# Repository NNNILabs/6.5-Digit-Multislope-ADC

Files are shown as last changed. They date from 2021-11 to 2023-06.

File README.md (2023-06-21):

# 6.5 Digit Multislope ADC
## Analog to digital converter than can resolve voltages down to 10uV

#### About

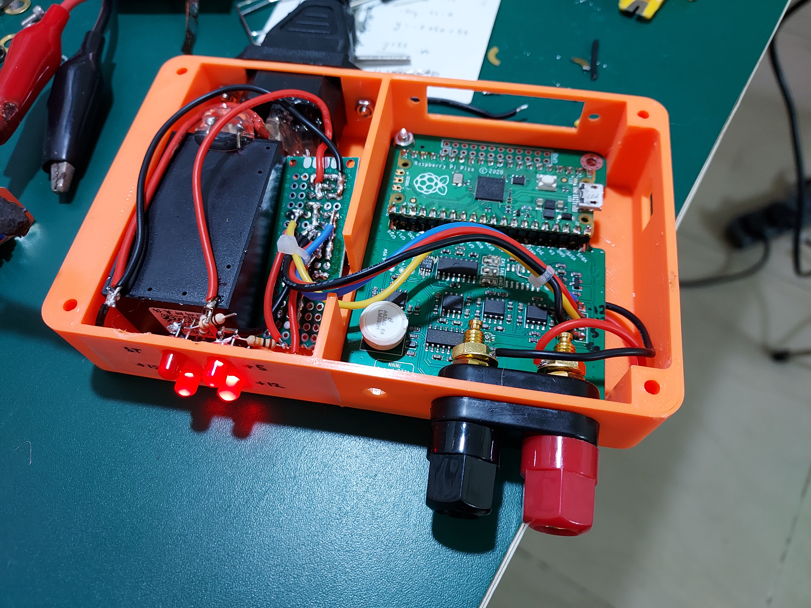
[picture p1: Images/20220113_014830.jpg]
ADC


The multislope topology fits comfortably between dual-slope and delta-sigma methods - very few precision components are needed to get very good results. Multislope is a charge balancing method - the input voltage is converted to a current (through the input resistor, one side of which is a virtual ground) and fed continuously into the integrator, and positive and negative reference voltages (which are converted to currents in the same way) are periodically injected into the integrator to maintain net zero charge. This is made possible using a clocked zero crossing comparator which determines which reference is to be switched into the inetgrator every clock cycle. 

This ADC has all the basic parts needed to operate it as a standalone +/-10V digitizer - an LM399 voltage reference, ref amps that convert the reference voltage to +/-10V, an input multiplexer, an input buffer, and the basic multislope components - a resistor network, an analog switch, a composite integrator, a fast comparator and a D latch. Using the on-board jumpers, this board can be configured to run in the "free-running" state (which can be considered a rudimentary delta-sigma method) and in PWM mode, with a constant number of switch transitions of remove errors due to analog switch charge injection.

Each measurement is taken over one power line cycle for normal mode rejection. The input is integrated over 6000 PWM cycles in 50Hz land and 5000 PWM cycles in 60Hz land. One power line cycle integration time gives around 16 bits resolution, 15 PLC is needed to achieve full 6.5 digits.

Each measurement cycle begins with "desaturation, which reads the comparator and slews the integrator to zero. Then the required number of PWM cycles are integrated, followed by rundown to read integrator residue. 

#### Statistics

-to be added-

#### Errata

- D Latch outputs are reversed if you want to use the ADC in free-running mode, luckily this can be changed easily by crossing over wires on the jumpers
- For the present PWM PIO code, the D latch has to be removed and the MEAS and SW-S3 pins have to be bridged together

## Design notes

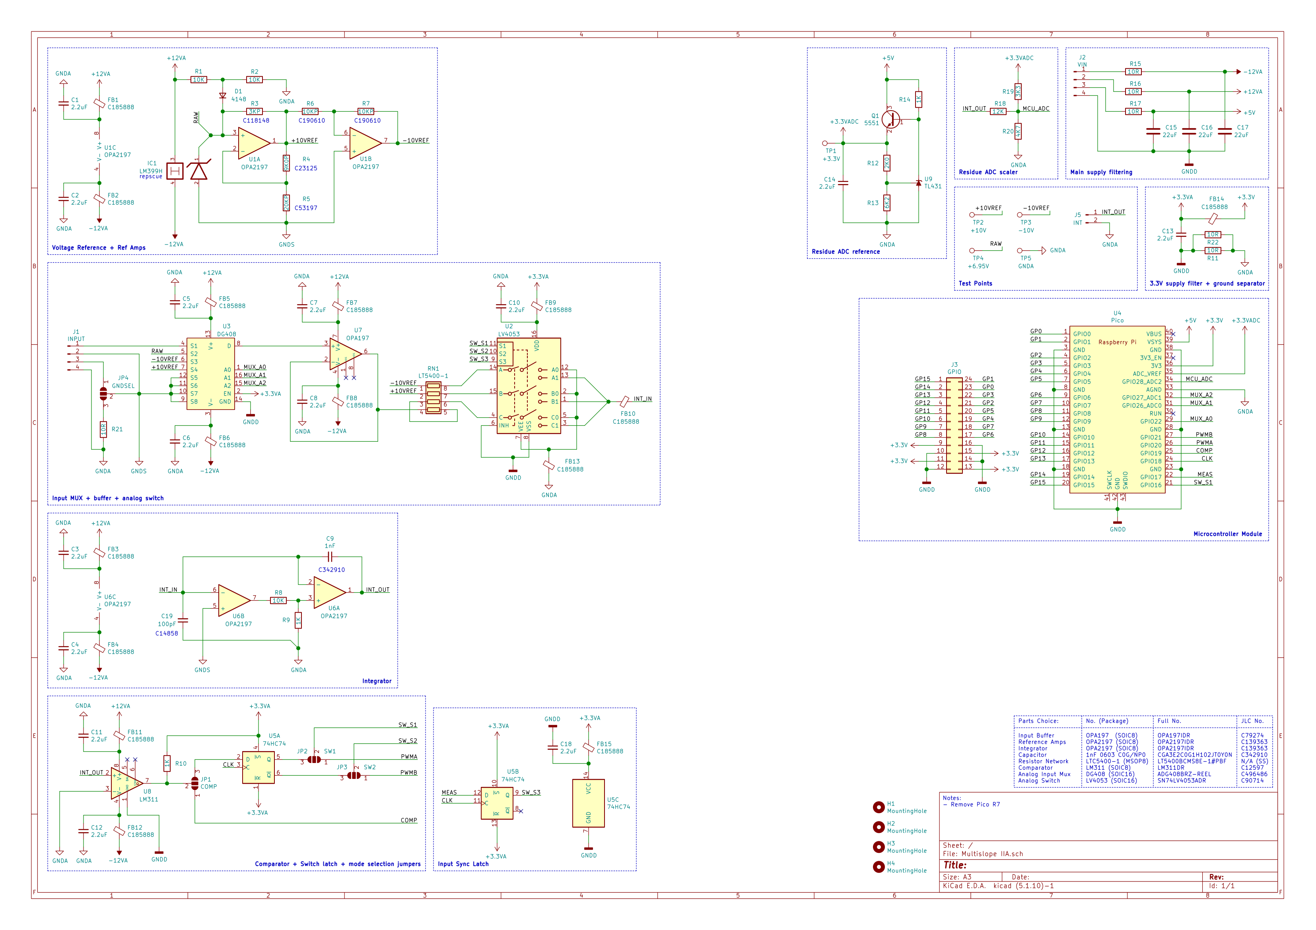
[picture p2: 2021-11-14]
PCB3/Multislope IIA-1.png

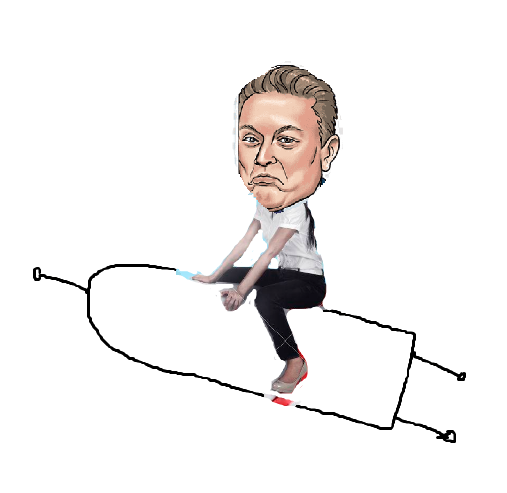
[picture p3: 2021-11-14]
PCB3/elongates.PNG

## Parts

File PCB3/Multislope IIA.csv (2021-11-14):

Comment | Designator | Footprint | LCSC Part #
2.2uF Unpolarized capacitor, small symbol | C1,C2,C3,C4,C5,C6,C7,C8,C10,C11,C12,C13,C14,C18 | C_0603_1608Metric | C23630
1nF Unpolarized capacitor, small symbol | C9 | C_0603_1608Metric | C342910
10uF Unpolarized capacitor | C15,C16,C17 | C_0603_1608Metric | C96446
100pF Unpolarized capacitor, small symbol | C19 | C_0603_1608Metric | C14858
4148 Diode, small symbol | D1 | D_SOD-323 | C2128
C185888 Ferrite bead, small symbol | FB1,FB2,FB3,FB4,FB5,FB6,FB7,FB8,FB9,FB10,FB11,FB12,FB13,FB14,FB15 | L_0603_1608Metric | C185888
MountingHole Mounting Hole without connection | H1,H2,H3,H4 | MountingHole_3mm_Pad_Via
LM399H | IC1 | TO-46-4
INPUT Generic connector, single row, 01x04, script generated (kicad-library-utils/schlib/autogen/connector/) | J1 | PinHeader_1x04_P2.54mm_Vertical
VIN Generic connector, single row, 01x04, script generated (kicad-library-utils/schlib/autogen/connector/) | J2 | PinHeader_1x04_P2.54mm_Vertical
GPIO Generic connector, double row, 02x12, counter clockwise pin numbering scheme (similar to DIP packge numbering), script generated (kicad-library-utils/schlib/autogen/connector/) | J3 | PinHeader_2x12_P2.54mm_Vertical
INT Generic connector, single row, 01x02, script generated (kicad-library-utils/schlib/autogen/connector/) | J5 | PinHeader_1x02_P1.27mm_Vertical
COMP Solder Jumper, 3-pole, open | JP1 | SolderJumper-3_P1.3mm_Open_Pad1.0x1.5mm
SW1 Solder Jumper, 3-pole, open | JP2 | SolderJumper-3_P1.3mm_Open_Pad1.0x1.5mm
SW2 Solder Jumper, 3-pole, open | JP3 | SolderJumper-3_P1.3mm_Open_Pad1.0x1.5mm
GNDSEL Solder Jumper, 3-pole, open | JP4 | SolderJumper-3_P1.3mm_Open_Pad1.0x1.5mm
5551 NPN transistor, base/emitter/collector | Q1 | SOT-23 | C2145
10K Resistor | R1,R2,R8 | R_0603_1608Metric | C25804
3KP Resistor | R3 | R_0603_1608Metric | C118148
9K0P Resistor | R4 | R_0603_1608Metric | C23125
20KP Resistor | R5 | R_0603_1608Metric | C53197
10KP Resistor | R6,R7 | R_0603_1608Metric | C190610
1K Resistor | R9,R10,R14 | R_0603_1608Metric | C21190
10R Resistor | R11,R15,R16,R17,R21,R22 | R_0603_1608Metric | C22859
2K0 Resistor | R12 | R_0603_1608Metric | C22975
6K2 Resistor | R13 | R_0603_1608Metric | C4260
12K Resistor | R18 | R_0603_1608Metric | C22790
3K3 Resistor | R19 | R_0603_1608Metric | C22978
4K7 Resistor | R20 | R_0603_1608Metric | C23162
LT5400-1 4 resistor network, parallel topology | RN1 | MSOP-8-1EP_3x3mm_P0.65mm_EP1.68x1.88mm
+3.3V test point | TP1 | TestPoint_Pad_D1.0mm
+10V test point | TP2 | TestPoint_Pad_D1.0mm
-10V test point | TP3 | TestPoint_Pad_D1.0mm
+6.95V test point | TP4 | TestPoint_Pad_D1.0mm
GNDA test point | TP5 | TestPoint_Pad_D1.0mm
OPA2197 Dual operational amplifier | U1,U6 | SOIC-8_3.9x4.9mm_P1.27mm | C139363
LV4053 CMOS triple 2-channel analog multiplexer/demultiplexer, TSSOP-16/DIP-16/SOIC-16 | U2 | SOIC-16_3.9x9.9mm_P1.27mm | C90714
DG408 | U3 | SOIC-16_3.9x9.9mm_P1.27mm | C496486
Pico | U4 | RPi_Pico_SMD_TH
74HC74 Dual D Flip-flop, Set & Reset | U5 | SOIC-14_3.9x8.7mm_P1.27mm | C6762
OPA197 Next Generation OP07 Ultralow Offset Voltage Operational Amplifier, DIP-8/TO-99-8 | U7 | SOIC-8_3.9x4.9mm_P1.27mm | C79274
LM311 Voltage Comparator, DIP-8/SOIC-8 | U8 | SOIC-8_3.9x4.9mm_P1.27mm | C12597
TL431 Shunt Regulator, SOT-23 | U9 | SOT-23 | C21235

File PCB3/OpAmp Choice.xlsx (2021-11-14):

Part Number | Package | Vos | Ib | Ios | Vos drift | en | in | Source | Single Available? | Used?
OPA2277UA/2K5 | SOIC-8 | 25uV | 4nA | 4nA | 1uV/C | 0.22uVpp, 8nV/rtHz | 0.2pA/rtHz | JLC | yes | No
OPA2180 | SOIC/SSOP8 | 75uV | 5nA | 3.5nA | 0.35uV/C | 0.25uVpp, 10nV/rtHz | 10fA/rtHz | Mouser | yes | No
OPA2197IDR | SOIC-8 | 100uV | 5nA | 2nA | 4.5uV/C | 1.3uVpp, 5.5nV/rtHz | 1.5fA/rtHz | JLC | yes | Yes
LT1013DDR | SOIC-8 | 400uV | 38nA | 3nA | 2.5uV/C | 0.55uVpp, 22nV/rtHz | 0.07pA/rtHz | JLC | n/a | No
OPA2227UA/2K5 | SOIC-8 | 200uV | 10nA | 10nA | 2uV/C | 90nVpp, 3nV/rtHz | 0.4pA/rtHz | JLC | expensive! | No
OPA1652AIDR | SOIC-8 | 1.5mV | 100pA | 100pA | 8uV/C | 5.4uVpp, 4.5nV/rtHz | 0.5pA/rtHz | JLC | n/a | No
OPA2211AIDDAR | SOIC-8 | 150uV | 250nA | 150nA | 0.85uV/C | 80nVpp, 1.1nV/rtHz | 1.7pA/rtHz | JLC | not in stock | No

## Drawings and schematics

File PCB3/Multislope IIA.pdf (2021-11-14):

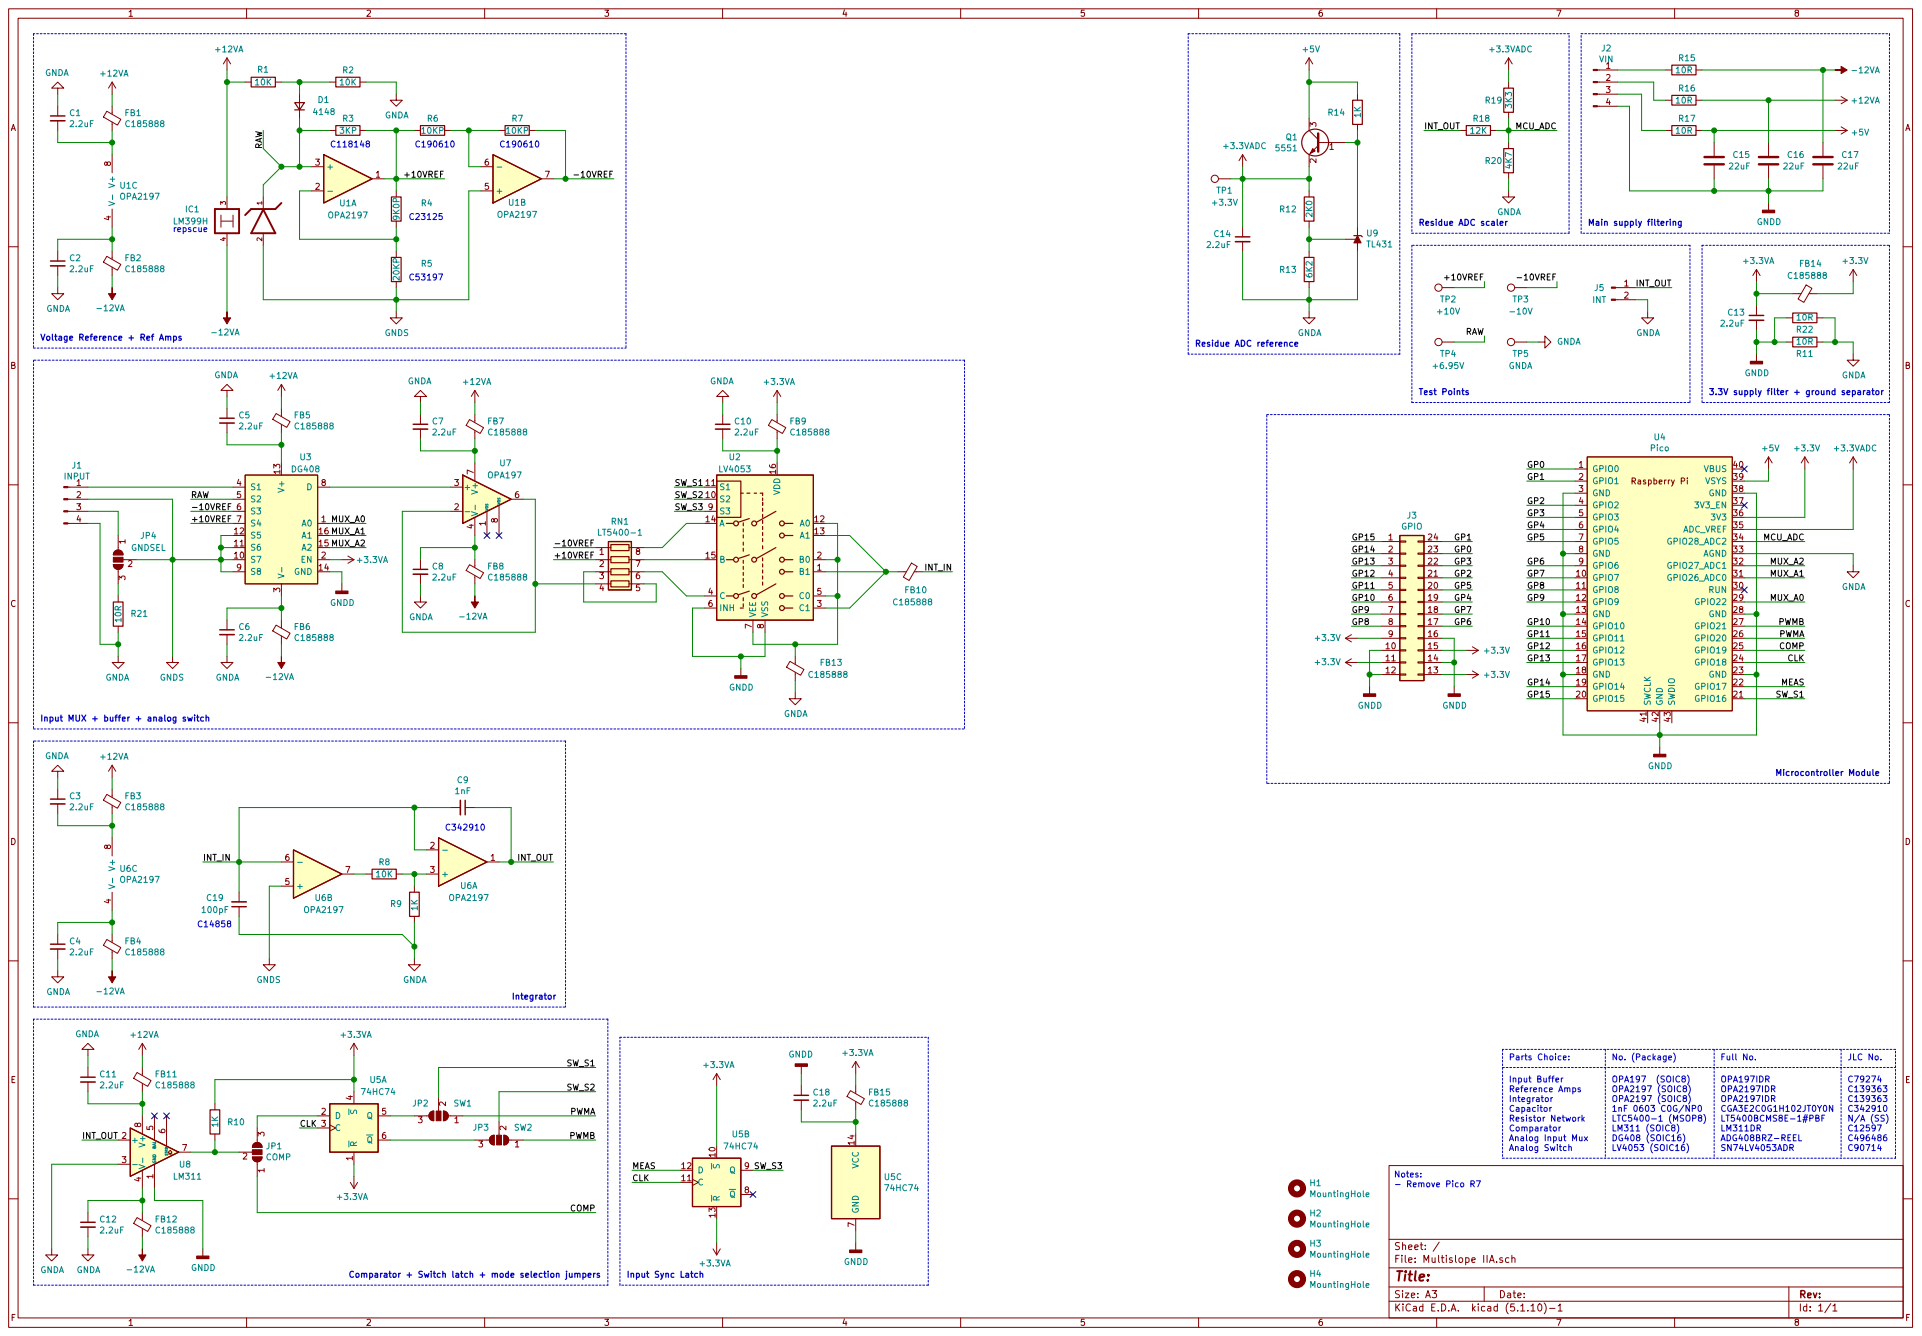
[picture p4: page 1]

Test Points Residue ADC reference Voltage Reference + Ref Amps

3.3V supply filter + ground separator C342910 Comparator + Switch latch + mode selection jumpers

Input MUX + buffer + analog switch

Analog Switch Parts Choice: Input Buffer Reference Amps Integrator Capacitor Resistor Network Comparator Analog Input Mux | OPA2197 (SOIC8) OPA2197 (SOIC8) 1nF 0603 C0G/NP0 LTC5400-1 (MSOP8) LM311 (SOIC8) DG408 (SOIC16) | OPA197IDR OPA2197IDR OPA2197IDR CGA3E2C0G1H102JT0Y0N LT5400BCMS8E-1#PBF LM311DR ADG408BRZ-REEL SN74LV4053ADR | C79274 C139363 C139363 C342910 N/A (SS) C12597 C496486 C90714 No. (Package)

Full No. | JLC No. OPA197 (SOIC8)

File: Multislope IIA.sch Sheet: /

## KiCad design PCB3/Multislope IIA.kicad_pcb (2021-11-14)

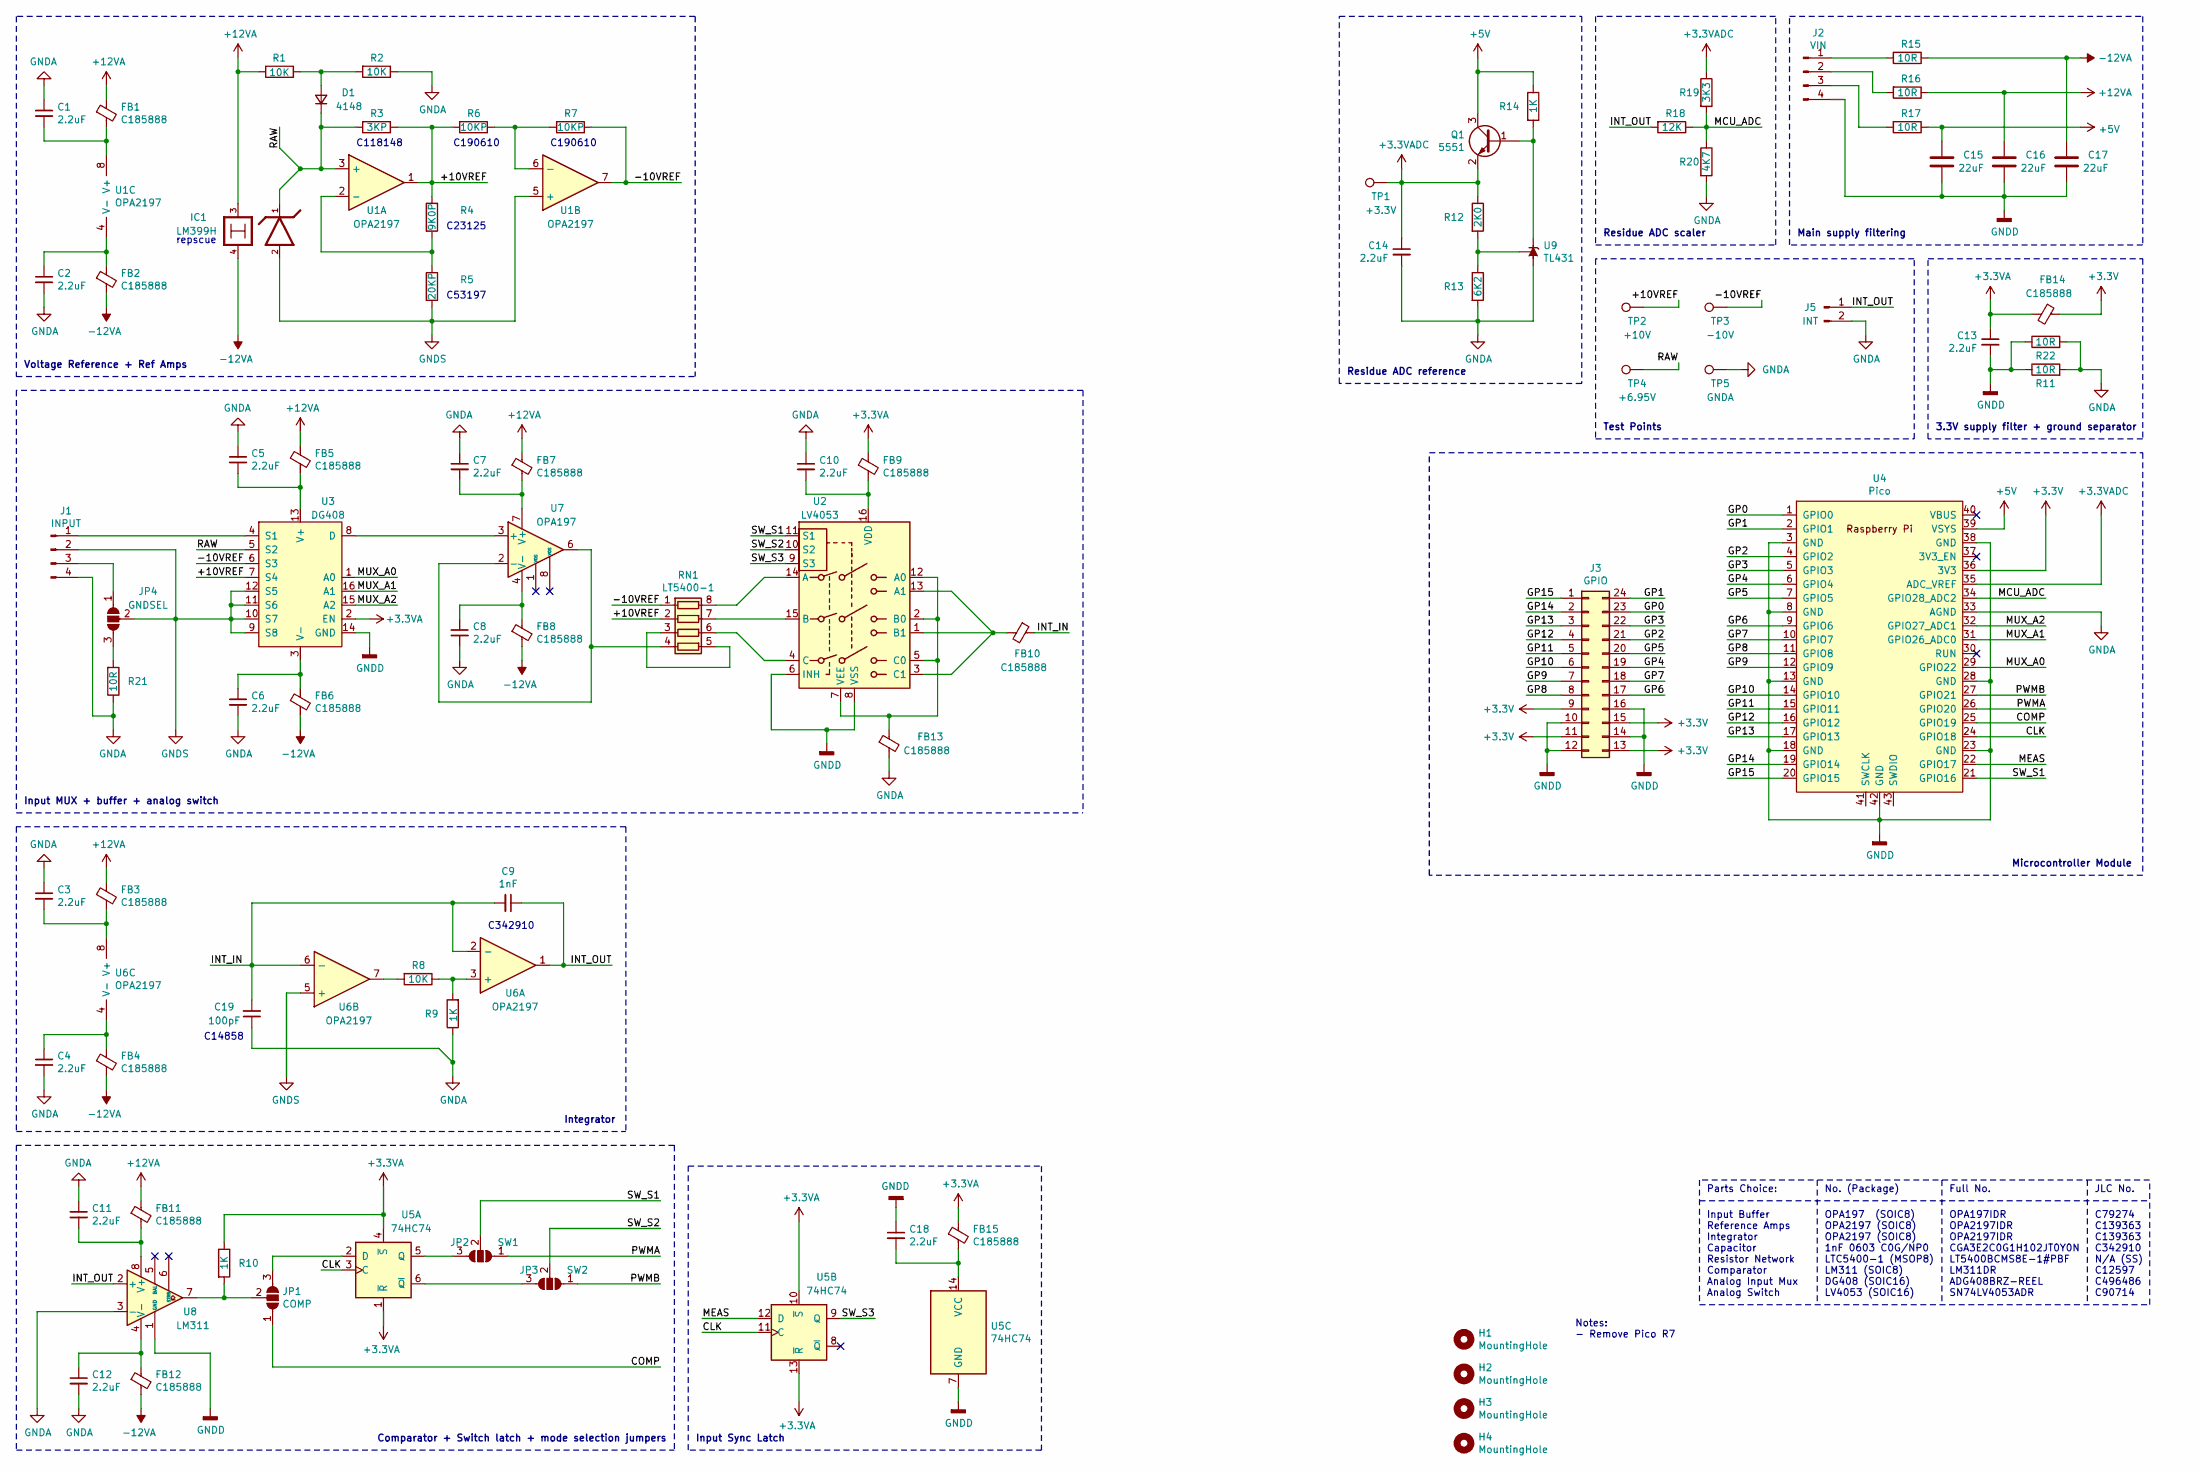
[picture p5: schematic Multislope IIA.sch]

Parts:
C1, C2, C3, C4, C5, C6, C7, C8, C10, C11, C12, C13, C14, C18: 2.2uF; C_0603_1608Metric
C9: 1nF; C_0603_1608Metric
C15, C16, C17: 22uF; C_0603_1608Metric
C19: 100pF; C_0603_1608Metric
D1: 4148; D_SOD-323
FB1, FB2, FB3, FB4, FB5, FB6, FB7, FB8, FB9, FB10, FB11, FB12, FB13, FB14, FB15: C185888; L_0603_1608Metric
H1, H2, H3, H4: MountingHole; MountingHole_3mm_Pad_Via
IC1: LM399H; TO-46-4
J1: INPUT; PinHeader_1x04_P2.54mm_Vertical
J2: VIN; PinHeader_1x04_P2.54mm_Vertical
J3: GPIO; PinHeader_2x12_P2.54mm_Vertical
J5: INT; PinHeader_1x02_P1.27mm_Vertical
JP1: COMP; SolderJumper-3_P1.3mm_Open_Pad1.0x1.5mm
JP2: SW1; SolderJumper-3_P1.3mm_Open_Pad1.0x1.5mm
JP3: SW2; SolderJumper-3_P1.3mm_Open_Pad1.0x1.5mm
JP4: GNDSEL; SolderJumper-3_P1.3mm_Open_Pad1.0x1.5mm
Q1: 5551; SOT-23
R1, R2, R8: 10K; R_0603_1608Metric
R3: 3KP; R_0603_1608Metric
R4: 9K0P; R_0603_1608Metric
R5: 20KP; R_0603_1608Metric
R6, R7: 10KP; R_0603_1608Metric
R9, R10, R14: 1K; R_0603_1608Metric
R11, R15, R16, R17, R21, R22: 10R; R_0603_1608Metric
R12: 2K0; R_0603_1608Metric
R13: 6K2; R_0603_1608Metric
R18: 12K; R_0603_1608Metric
R19: 3K3; R_0603_1608Metric
R20: 4K7; R_0603_1608Metric
RN1: LT5400-1; MSOP-8-1EP_3x3mm_P0.65mm_EP1.68x1.88mm
TP1: +3.3V; TestPoint_Pad_D1.0mm
TP2: +10V; TestPoint_Pad_D1.0mm
TP3: -10V; TestPoint_Pad_D1.0mm
TP4: +6.95V; TestPoint_Pad_D1.0mm
TP5: GNDA; TestPoint_Pad_D1.0mm
U1, U6: OPA2197; SOIC-8_3.9x4.9mm_P1.27mm
U2: LV4053; SOIC-16_3.9x9.9mm_P1.27mm
U3: DG408; SOIC-16_3.9x9.9mm_P1.27mm
U4: Pico; RPi_Pico_SMD_TH
U5: 74HC74; SOIC-14_3.9x8.7mm_P1.27mm
U7: OPA197; SOIC-8_3.9x4.9mm_P1.27mm
U8: LM311; SOIC-8_3.9x4.9mm_P1.27mm
U9: TL431; SOT-23

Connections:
+3.3VA: C13.1, FB9.1, FB14.2, FB15.1, R10.1, U3.2 (EN), U5.1 (~R), U5.4 (~S), U5.10 (~S), U5.13 (~R)
+3.3VADC: C14.1, Q1.2 (E), R12.1, R19.1, TP1.1, U4.35 (ADC_VREF)
+3V3: FB14.1, J3.9, J3.11, J3.13, J3.15, U4.36 (3V3)
+5V: C15.1, Q1.3 (C), R14.1, R17.1, U4.39 (VSYS)
+12VA: C16.1, FB1.1, FB3.1, FB5.1, FB7.1, FB11.1, IC1.3, R1.1, R16.1
-12VA: C17.1, FB2.2, FB4.2, FB6.2, FB8.2, FB12.2, IC1.4, R15.1
/+10VREF: R3.1, R4.1, R6.2, RN1.2 (R2.1), TP2.1, U1.1, U3.7 (S4)
/-10VREF: R7.1, RN1.1 (R1.1), TP3.1, U1.7, U3.6 (S3)
/CLK: U4.24 (GPIO18), U5.3 (C), U5.11 (C)
/COMP: JP1.1 (A), U4.25 (GPIO19)
/GP0: J3.23, U4.1 (GPIO0)
/GP1: J3.24, U4.2 (GPIO1)
/GP2: J3.21, U4.4 (GPIO2)
/GP3: J3.22, U4.5 (GPIO3)
/GP4: J3.19, U4.6 (GPIO4)
/GP5: J3.20, U4.7 (GPIO5)
/GP6: J3.17, U4.9 (GPIO6)
/GP7: J3.18, U4.10 (GPIO7)
/GP8: J3.8, U4.11 (GPIO8)
/GP9: J3.7, U4.12 (GPIO9)
/GP10: J3.6, U4.14 (GPIO10)
/GP11: J3.5, U4.15 (GPIO11)
/GP12: J3.4, U4.16 (GPIO12)
/GP13: J3.3, U4.17 (GPIO13)
/GP14: J3.2, U4.19 (GPIO14)
/GP15: J3.1, U4.20 (GPIO15)
/INT_IN: C9.2, C19.2, FB10.1, U6.2 (-), U6.6 (-)
/INT_OUT: C9.1, J5.1, R18.2, U6.1, U8.2 (+)
/MCU_ADC: R18.1, R19.2, R20.1, U4.34 (GPIO28_ADC2)
/MEAS: U4.22 (GPIO17), U5.12 (D)
/MUX_A0: U3.1 (A0), U4.29 (GPIO22)
/MUX_A1: U3.16 (A1), U4.31 (GPIO26_ADC0)
/MUX_A2: U3.15 (A2), U4.32 (GPIO27_ADC1)
/PWMA: JP2.1 (A), U4.26 (GPIO20)
/PWMB: JP3.1 (A), U4.27 (GPIO21)
/RAW: D1.1 (K), IC1.1, R3.2, TP4.1, U1.3 (+), U3.5 (S2)
/SW_S1: JP2.2 (C), U2.11 (S1), U4.21 (GPIO16)
/SW_S2: JP3.2 (C), U2.10 (S2)
/SW_S3: U2.9 (S3), U5.9 (Q)
GNDA: C1.1, C2.2, C3.1, C4.2, C5.1, C6.2, C7.1, C8.2, C10.1, C11.1, C12.2, C14.2, C19.1, FB13.2, J1.4, J5.2, R2.1, R9.1, R11.2, R13.2, R20.2, R21.1, R22.2, TP5.1, U4.33 (AGND), U8.3 (-), U9.3 (A)
GNDD: C13.2, C15.2, C16.2, C17.2, C18.1, J2.4, J3.10, J3.12, J3.14, J3.16, R11.1, R22.1, U2.6 (INH), U2.8 (VSS), U3.14 (GND), U4.3 (GND), U4.8 (GND), U4.13 (GND), U4.18 (GND), U4.23 (GND), U4.28 (GND), U4.38 (GND), U4.42 (GND), U5.7 (GND), U8.1 (GND)
GNDS: IC1.2, J1.2, JP4.2 (C), R5.2, U1.5 (+), U3.9 (S8), U3.10 (S7), U3.11 (S6), U3.12 (S5), U6.5 (+)
unnamed: C1.2, FB1.2, U1.8 (V+)
unnamed: C2.1, FB2.1, U1.4 (V-)
unnamed: C3.2, FB3.2, U6.8 (V+)
unnamed: C4.1, FB4.1, U6.4 (V-)
unnamed: C5.2, FB5.2, U3.13 (V+)
unnamed: C6.1, FB6.1, U3.3 (V-)
unnamed: C7.2, FB7.2, U7.7 (V+)
unnamed: C8.1, FB8.1, U7.4 (V-)
unnamed: C10.2, FB9.2, U2.16 (VDD)
unnamed: C11.2, FB11.2, U8.8 (V+)
unnamed: C12.1, FB12.1, U8.4 (V-)
unnamed: C18.2, FB15.2, U5.14 (VCC)
unnamed: D1.2 (A), R1.2, R2.2
unnamed: FB10.2, U2.1 (B1), U2.3 (C1), U2.13 (A1)
unnamed: FB13.1, U2.2 (B0), U2.5 (C0), U2.7 (VEE), U2.12 (A0)
unnamed: J1.1, U3.4 (S1)
unnamed: J1.3, JP4.1 (A)
unnamed: J2.1, R15.2
unnamed: J2.2, R16.2
unnamed: J2.3, R17.2
unnamed: JP1.2 (C), R10.2, U8.7
unnamed: JP1.3 (B), U5.2 (D)
unnamed: JP2.3 (B), U5.5 (Q)
unnamed: JP3.3 (B), U5.6 (~Q)
unnamed: JP4.3 (B), R21.2
unnamed: Q1.1 (B), R14.2, U9.1 (K)
unnamed: R4.2, R5.1, U1.2 (-)
unnamed: R6.1, R7.2, U1.6 (-)
unnamed: R8.1, R9.2, U6.3 (+)
unnamed: R8.2, U6.7
unnamed: R12.2, R13.1, U9.2 (REF)
unnamed: RN1.3 (R3.1), RN1.5 (R4.2)
unnamed: RN1.4 (R4.1), U7.2 (-), U7.6
unnamed: RN1.6 (R3.2), U2.4 (C)
unnamed: RN1.7 (R2.2), U2.15 (B)
unnamed: RN1.8 (R1.2), U2.14 (A)
unnamed: U3.8 (D), U7.3 (+)

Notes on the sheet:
C23125
C53197
C118148
Input Buffer Reference Amps Integrator Capacitor Resistor Network Comparator Analog Input Mux Analog Switch
OPA197 (SOIC8) OPA2197 (SOIC8) OPA2197 (SOIC8) 1nF 0603 C0G/NP0 LTC5400-1 (MSOP8) LM311 (SOIC8) DG408 (SOIC16) LV4053 (SOIC16)
OPA197IDR OPA2197IDR OPA2197IDR CGA3E2C0G1H102JT0Y0N LT5400BCMS8E-1#PBF LM311DR ADG408BRZ-REEL SN74LV4053ADR
C190610
C190610
repscue
C342910
Parts Choice:
C79274 C139363 C139363 C342910 N/A (SS) C12597 C496486 C90714
No. (Package)
Full No.
JLC No.
Notes: - Remove Pico R7
Voltage Reference + Ref Amps
Input MUX + buffer + analog switch
Integrator
Comparator + Switch latch + mode selection jumpers
Main supply filtering
Residue ADC reference
Residue ADC scaler
3.3V supply filter + ground separator
Input Sync Latch
Microcontroller Module
C14858
Test Points

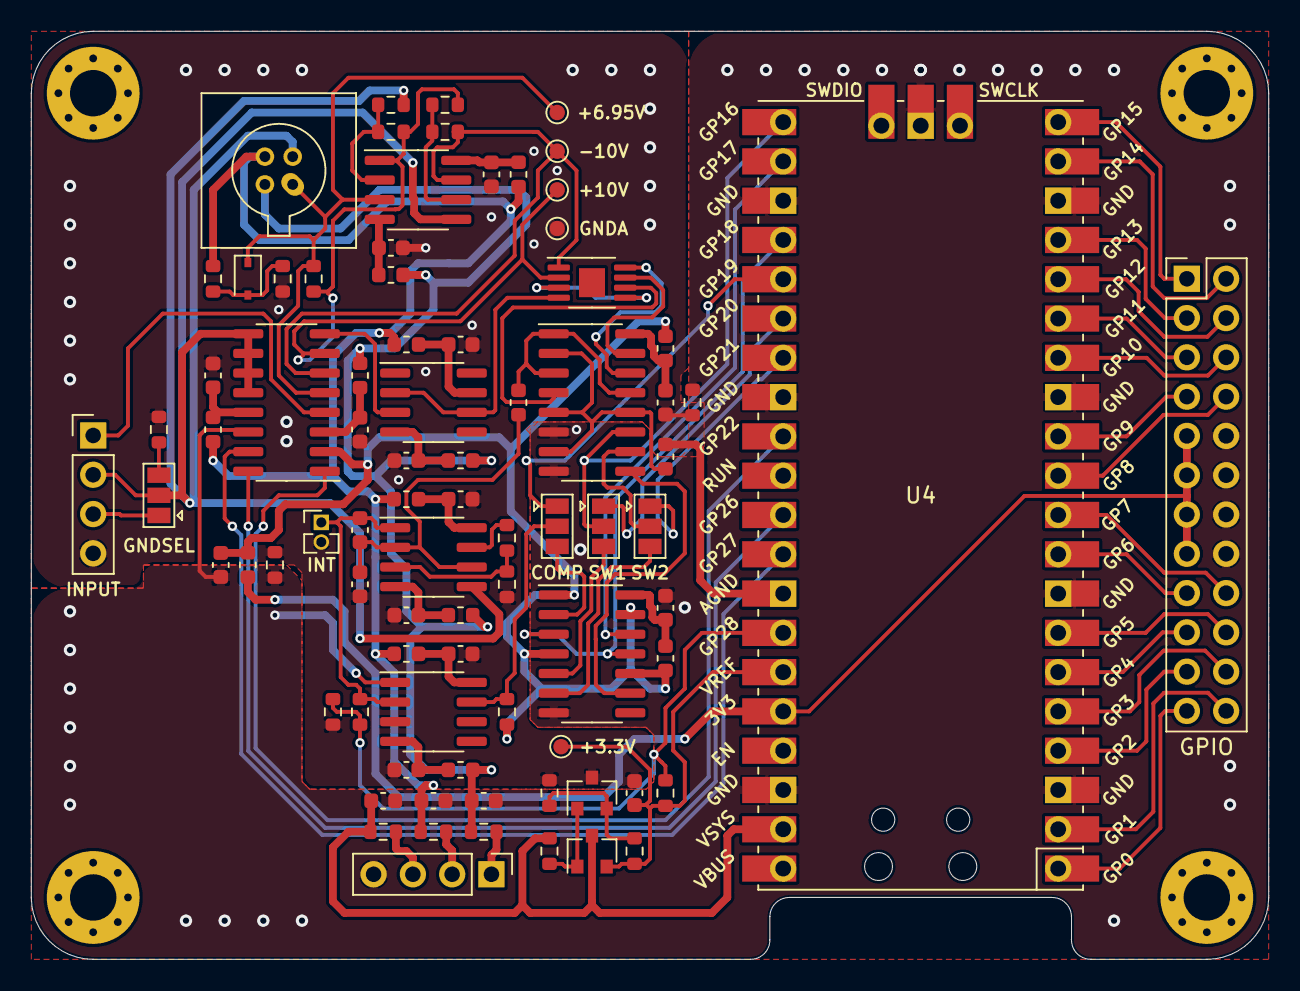
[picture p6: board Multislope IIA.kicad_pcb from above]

Board: 2 copper layers, 80.0 x 60.0 mm, 86 parts (0 on the bottom side), 79 nets.

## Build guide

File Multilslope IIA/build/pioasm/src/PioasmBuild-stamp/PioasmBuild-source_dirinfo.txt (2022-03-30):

# This is a generated file and its contents are an internal implementation detail.
# The download step will be re-executed if anything in this file changes.
# No other meaning or use of this file is supported.

method=source_dir
command=
source_dir=C:/VSARM/sdk/pico/pico-sdk/tools/pioasm
work_dir=

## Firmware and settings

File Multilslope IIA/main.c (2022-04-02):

#include "pico/stdlib.h"
#include "hardware/pio.h"
#include "hardware/clocks.h"
#include "ms.pio.h"

int main()
{
    set_sys_clock_khz(100000, true); //100Mhz main for testing, 96MHz for real thing

    static const uint ledPin = 0;
    static const uint PWMA = 20;
    static const uint PWMB = 21;
    static const uint COMP = 19;
    static const uint MEAS = 17;

    uint32_t pushVar = 1000;
    uint32_t counts = 0;
    uint32_t postCounts = 0;

    PIO pio = pio0;

    uint sm = pio_claim_unused_sm(pio, true);
    uint offset = pio_add_program(pio, &ms_program);

    gpio_init(ledPin);
    gpio_set_dir(ledPin, GPIO_OUT);

    float div = 10; //100MHz main and 10MHz PIO for testing, div = 10 for real thing
    /*
    Multislope timings
    Processor clock     : 96Mhz
    PIO clock           : 9.6MHz
    PWM frequency       : 300kHz
    Clock per PWM       : 32 cycles
    Duty cycle          : 1/16, 15/16
    PLC         @50Hz   : 6000 PWM cycles
                @60Hz   : 5000 PWM cycles
    Pre-rundown         : 32 clock cycles
    */
    
    ms_program_init(pio, sm, offset, PWMA, MEAS, COMP, div);

    while (true)
    {
        pio_sm_put_blocking(pio, sm, pushVar);
        pio_sm_set_enabled(pio, sm, true);
        gpio_put(ledPin, true);
        //counts = ~pio_sm_get_blocking(pio, sm);
        //postCounts = ~pio_sm_get_blocking(pio, sm);
        gpio_put(ledPin, false);
        pio_sm_set_enabled(pio, sm, false);
        sleep_ms(1000);
    }
}
